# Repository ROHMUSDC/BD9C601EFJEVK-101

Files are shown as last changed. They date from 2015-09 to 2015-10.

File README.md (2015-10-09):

# BD9C601EFJEVK-101 Design Resource Repository
* Hardware Design Files and Documentation for the ROHM BD9C601EFJEVK-101 EVK

----
### Description: 
* BD9C601EFJ is a synchronous buck switching regulator with built-in low on-resistance power MOSFETs
* With wide input voltage range, It is capable of providing current of up to 6A
* It is a current mode control DC/DC converter and features high-speed transient response
* Phase compensation can also be set easily

----
### Repository Contents
* Application Note Folder: Contains Draft Version of EVK Application Note
* Design Files: Contains Board, Gerber, Schematic, and BOM information for this EVK Board
* Measurement Reports Folder: Contains measurement testing information completed for these EVK Boards

----
### Where to Purchase?
* http://www.rohm.com/web/global/distribution/-/dinventory/BD9C601EFJ_EVK/sample/0

----
### DISCLAIMER
This Technical Data is protected under copyright laws.

ROHM hereby grants you a nonexclusive, nontransferable license to use this Technical Data 
as long as you abide by the terms and conditions of this DISCLAIMER. 

However, you are not authorized to sell, loan, rent, lease, redistribute or license this Technical Data, 
in whole or in part, or in modified form, to anyone.

You may modify this Technical Data to suit your specific applications, 
but the rights to derivative works and said modifications shall belong to ROHM. 

You may make copies of this Technical Data as necessary for internal use only within your company.

In any case, the latest datasheet is considered the final design guideline and represents 
the only actual performance specifications.

ROHM shall not be responsible for ensuring proper application on all computer systems.
This Technical Data is provided AS IS. ROHM makes no guarantees, either implicitly or explicitly, 
regarding its usability, functionality, accuracy, merchantability, or fitness for a specific purpose.

In addition, you shall take full responsibility for the use of any information acquired from this Technical Data. 

ROHM does not assume warranty of any kind arising from the use of this Technical Data. ACCORDINGLY, 
IN NO EVENT SHALL ROHM BE RESPONSIBLE, WHETHER THROUGH CONTRACT OR TORT LIABILITY, 
FOR ANY DAMAGES (INCLUDING BUT NOT LIMITED TO LOST PROFITS OR OTHER INCIDENTAL, CONSEQUENTAL, 
OR PUNITIVE DAMAGES) ARISING OUT OF OR IN CONNECTION WITH THE USE OR APPLICATION OF THIS Technical Data.

Furthermore, this Technical Data is subject to change without notice.

Unless otherwise expressly provided herein, ROHM does not convey any license under patent rights 
or any other intellectual property rights (including those of third parties).

ROHM is not obligated to provide maintenance or support for the Technical Data.

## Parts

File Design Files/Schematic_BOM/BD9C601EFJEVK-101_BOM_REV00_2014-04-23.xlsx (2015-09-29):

BD9C601EFJEVK-101
Revision: 00
Bill Of Materials | Page1
Item | Quantity | Reference | Part | PCB Footprint | DESCRIPTION | MANUFACTURER1 | MANUFACTURER1_PART# | DISTR1 | DISTR1_PART# | DNP | Provided by ROHM | ROHM Comment
1 | 1 | C1 | 0.1uF | C0603 | CAP CER 0.1UF 25V 10% X7R 0603 | Murata | GRM188R71E104KA01D | DIGIKEY | 490-1524-2-ND |  | Y
2 | 1 | C2 | 10uF | C1206 | CAP CER 10UF 25V 20% X5R 1206 | Murata | GRM31CR61E106MA12L | DIGIKEY | 490-5423-1-ND |  | Y
3 | 2 | C3,C4 | 22uF | C1206 | CAP CER 22UF 16V 10% X5R 1206 | Murata | GRM31CR61C226KE15K | DIGIKEY | 490-6512-1-ND |  | Y
4 | 1 | C5 |  | C0603 |  |  |  |  |  | DNP( Do not place)
5 | 1 | C6 | 1500pF | C0603 | CAP CER 1500PF 50V 10% X7R 0603 | Murata | GRM188R71H152KA01D | DIGIKEY | 490-1498-2-ND |  | Y
6 | 1 | C7 |  | C1206 |  |  |  |  |  | DNP( Do not place)
7 | 1 | C8 |  | C0805 |  |  |  |  |  | DNP( Do not place)
8 | 2 | D1,D3 | RB085B-30TL | CPD | DIODE SCHOTTKY 30V 10A CPD | Rohm | RB085B-30TL | DIGIKEY | RB085B-30TLCT-ND | DNP( Do not place) | Y
9 | 1 | D2 | SMAJ16A | DO-214AC | TVS DIODE 16VWM 26VC SMA | Littelfuse Inc | SMAJ16A | DIGIKEY | SMAJ16ALFTR-ND |  | N
10 | 1 | J1 | 87224-3 | HDR_THVT_1X3_100 | CONN HEADER VERT .100 3POS 15AU | TE Connectivity Div | 87224-3 | DIGIKEY | A26545-ND |  | N
11 | 1 | L1 | 3.3uH | SMT_7P1X6P5 | INDUCTOR 3.3UH 6.8A 20% SMD | TDK Corporation | SPM6530T-3R3M | DIGIKEY | 445-4119-2-ND |  | Y
12 | 1 | R1 | 20K | R0603 | RES 20K OHM 1/10W 1% 0603 SMD | Rohm | TRR03EZPF2002 | DIGIKEY | RHM20KBJTR-ND |  | Y
13 | 1 | R2 | 7.5K | R0603 | RES 7.5K OHM 1/10W 1% 0603 SMD | Rohm | MCR03ERTF7501 | DIGIKEY | RHM7.50KCFTR-ND |  | Y
14 | 1 | R3 | 2.4K | R0603 | RES 2.4K OHM 1/10W 1% 0603 SMD | Rohm | MCR03ERTF2401 | DIGIKEY | RHM2.40KCFTR-ND |  | Y
15 | 2 | TP1,TP3 | TP_63Mil_TH | TP_TH | TEST POINT PC MULTI PURPOSE RED | Keystone Electronics | 5010 | DIGIKEY | 5010K-ND |  | N
16 | 2 | TP2,TP4 | TP_63Mil_TH | TP_TH | TEST POINT PC MULTI PURPOSE BLK | Keystone Electronics | 5011 | DIGIKEY | 5011K-ND |  | N
17 | 1 | U1 | BD9C601EFJ | HTSOP-J8 | 4.5V to 18V Input, 6.0A Integrated MOSFET 1ch Synchronous Buck DC/DC Converter | ROHM | BD9C601EFJ |  |  |  | Y
18 | 1 | ZX1 | 0 | SM_180x060 | 1806 footprint solder-short during assembly
19 |  |  |  |  | Shunt jumper for header J1 (item #10), CONN SHUNT 2POS GOLD W/HANDLE | TE Connectivity | 881545-1 | DIGIKEY | 881545-1-ND |  | N

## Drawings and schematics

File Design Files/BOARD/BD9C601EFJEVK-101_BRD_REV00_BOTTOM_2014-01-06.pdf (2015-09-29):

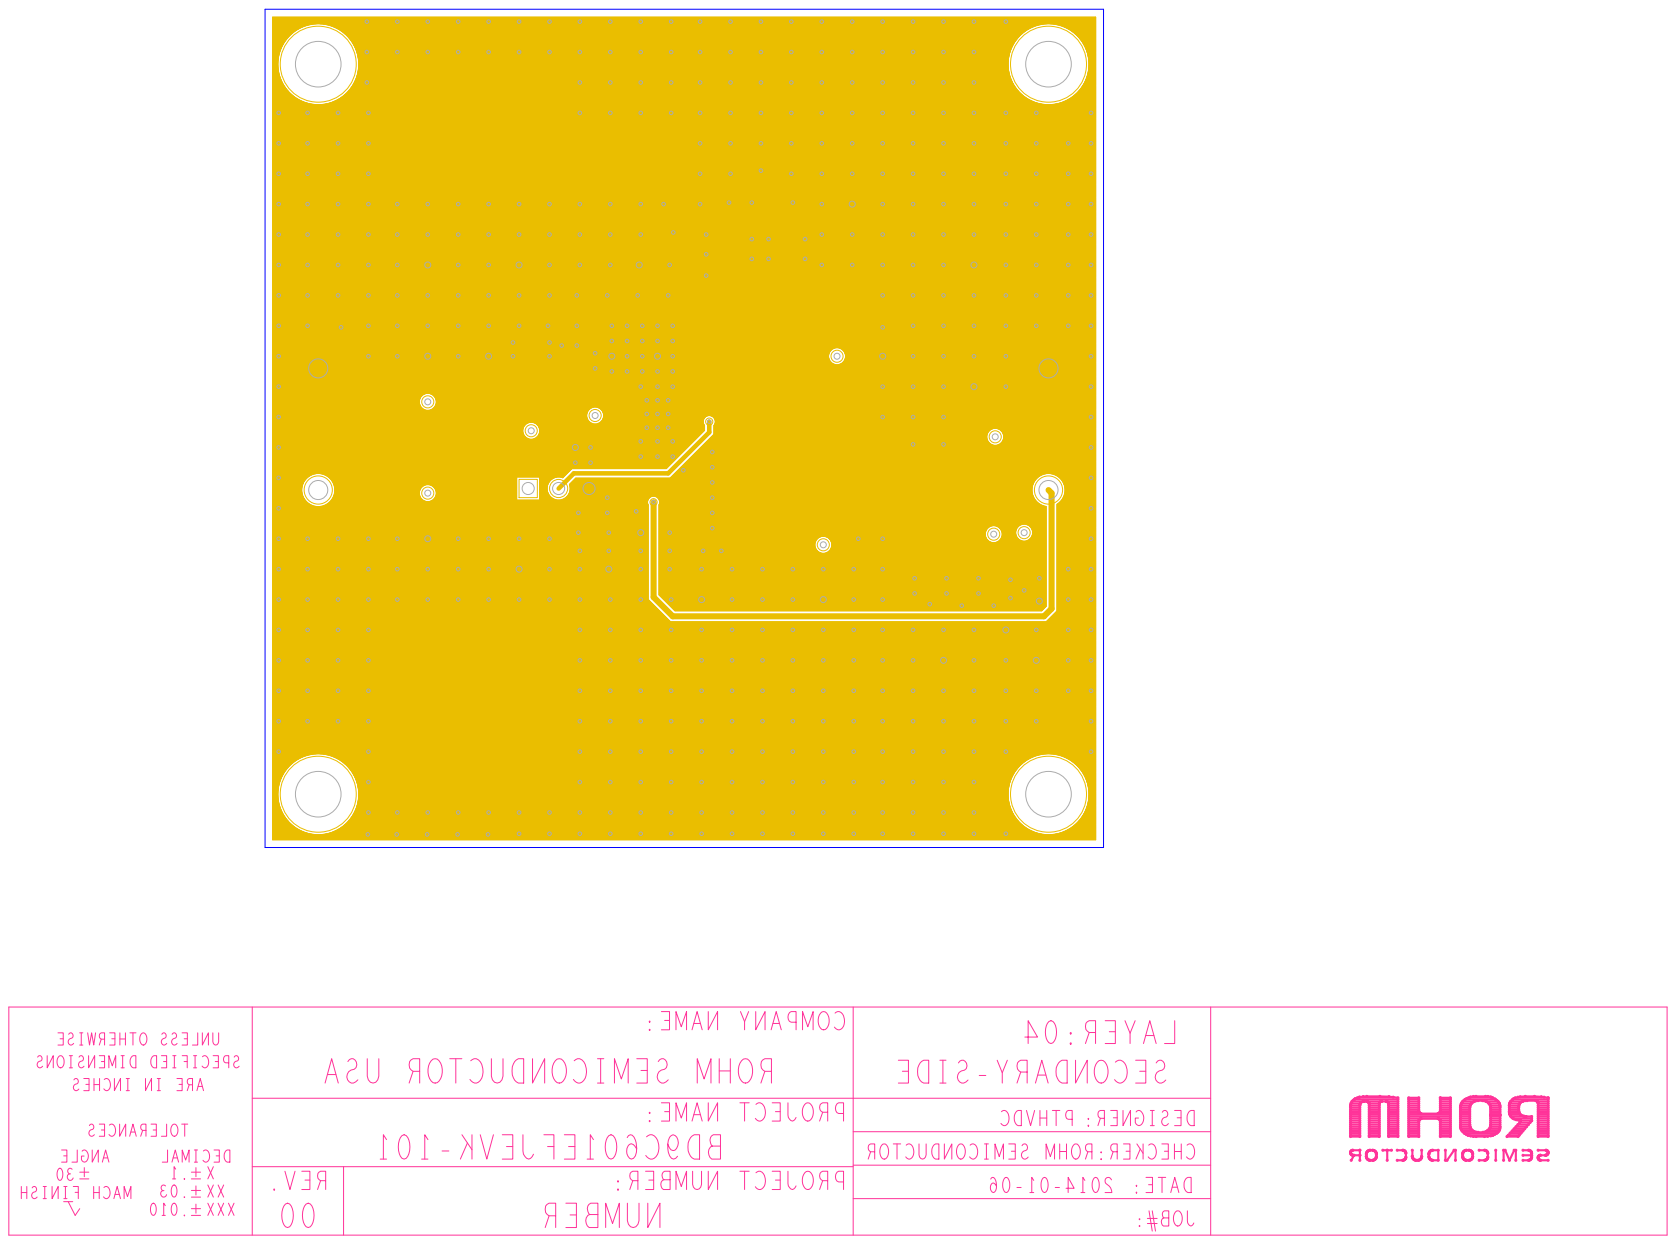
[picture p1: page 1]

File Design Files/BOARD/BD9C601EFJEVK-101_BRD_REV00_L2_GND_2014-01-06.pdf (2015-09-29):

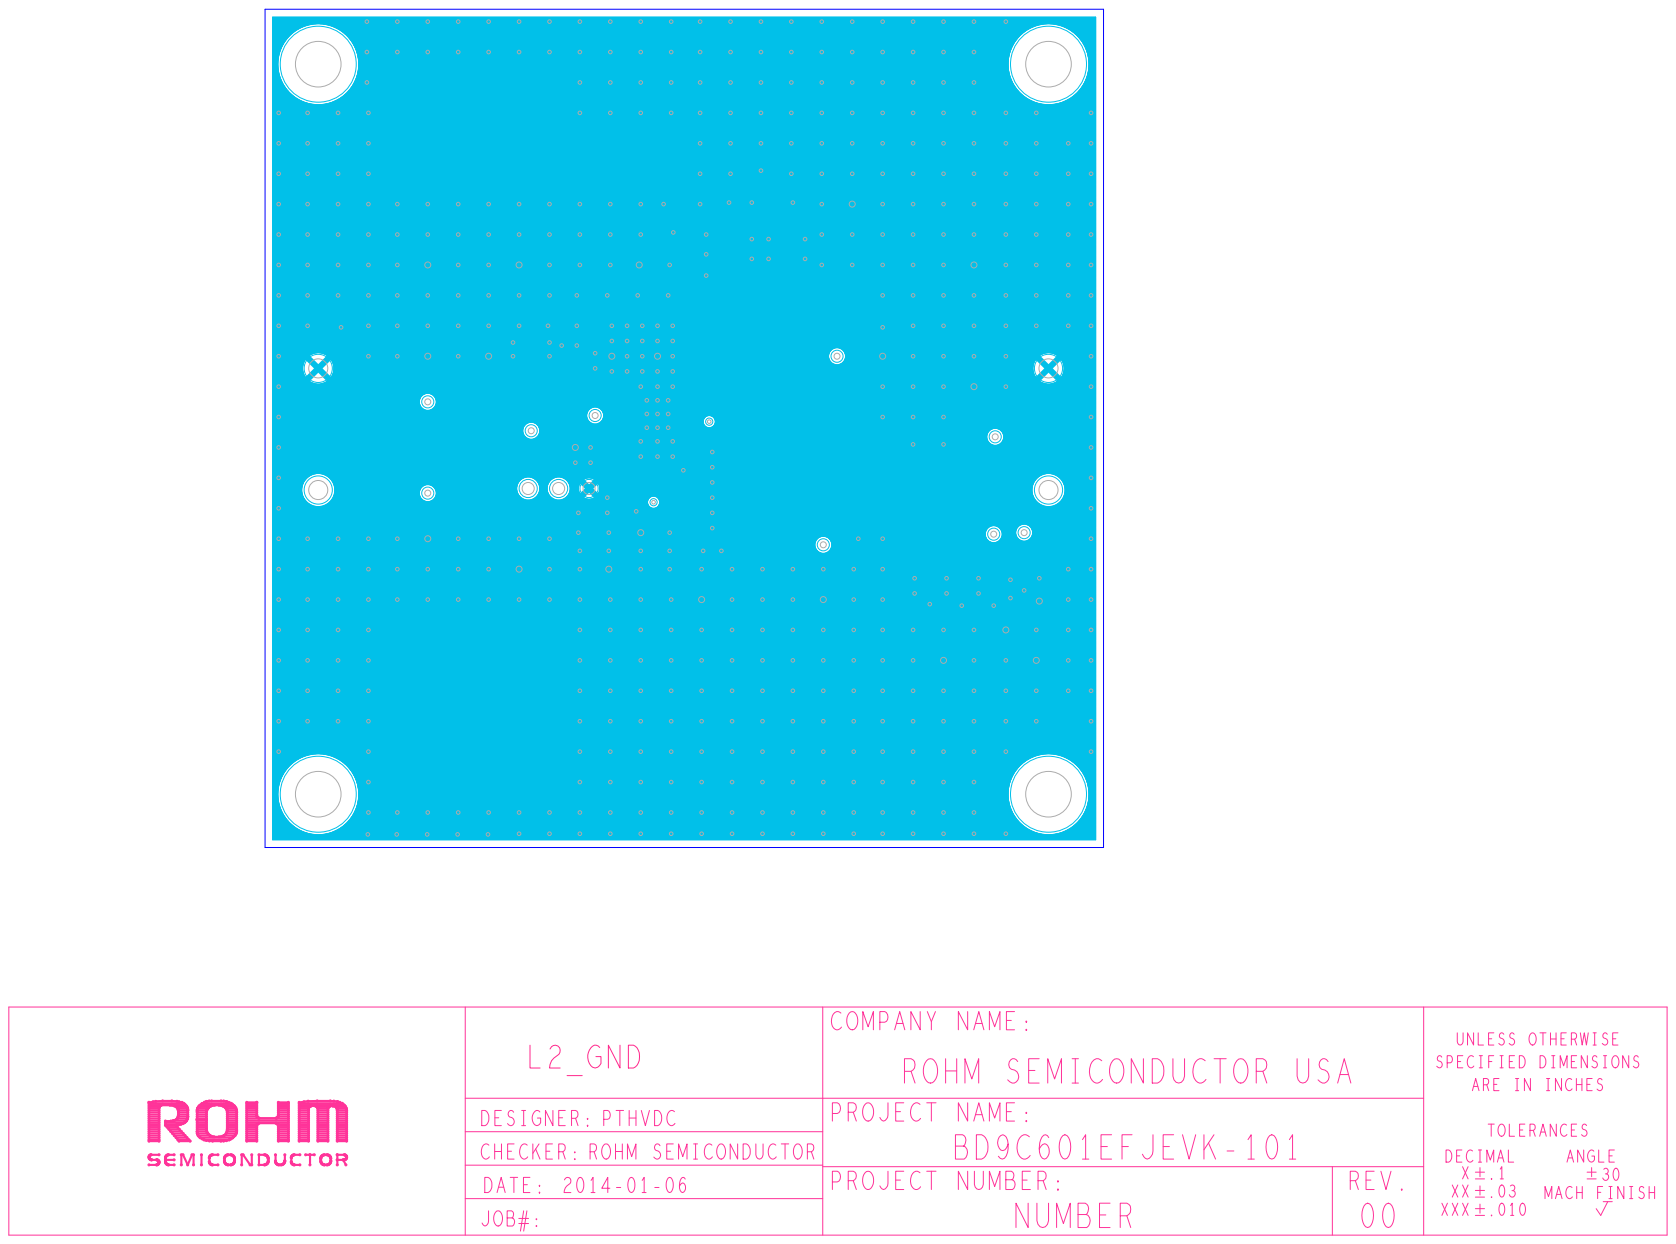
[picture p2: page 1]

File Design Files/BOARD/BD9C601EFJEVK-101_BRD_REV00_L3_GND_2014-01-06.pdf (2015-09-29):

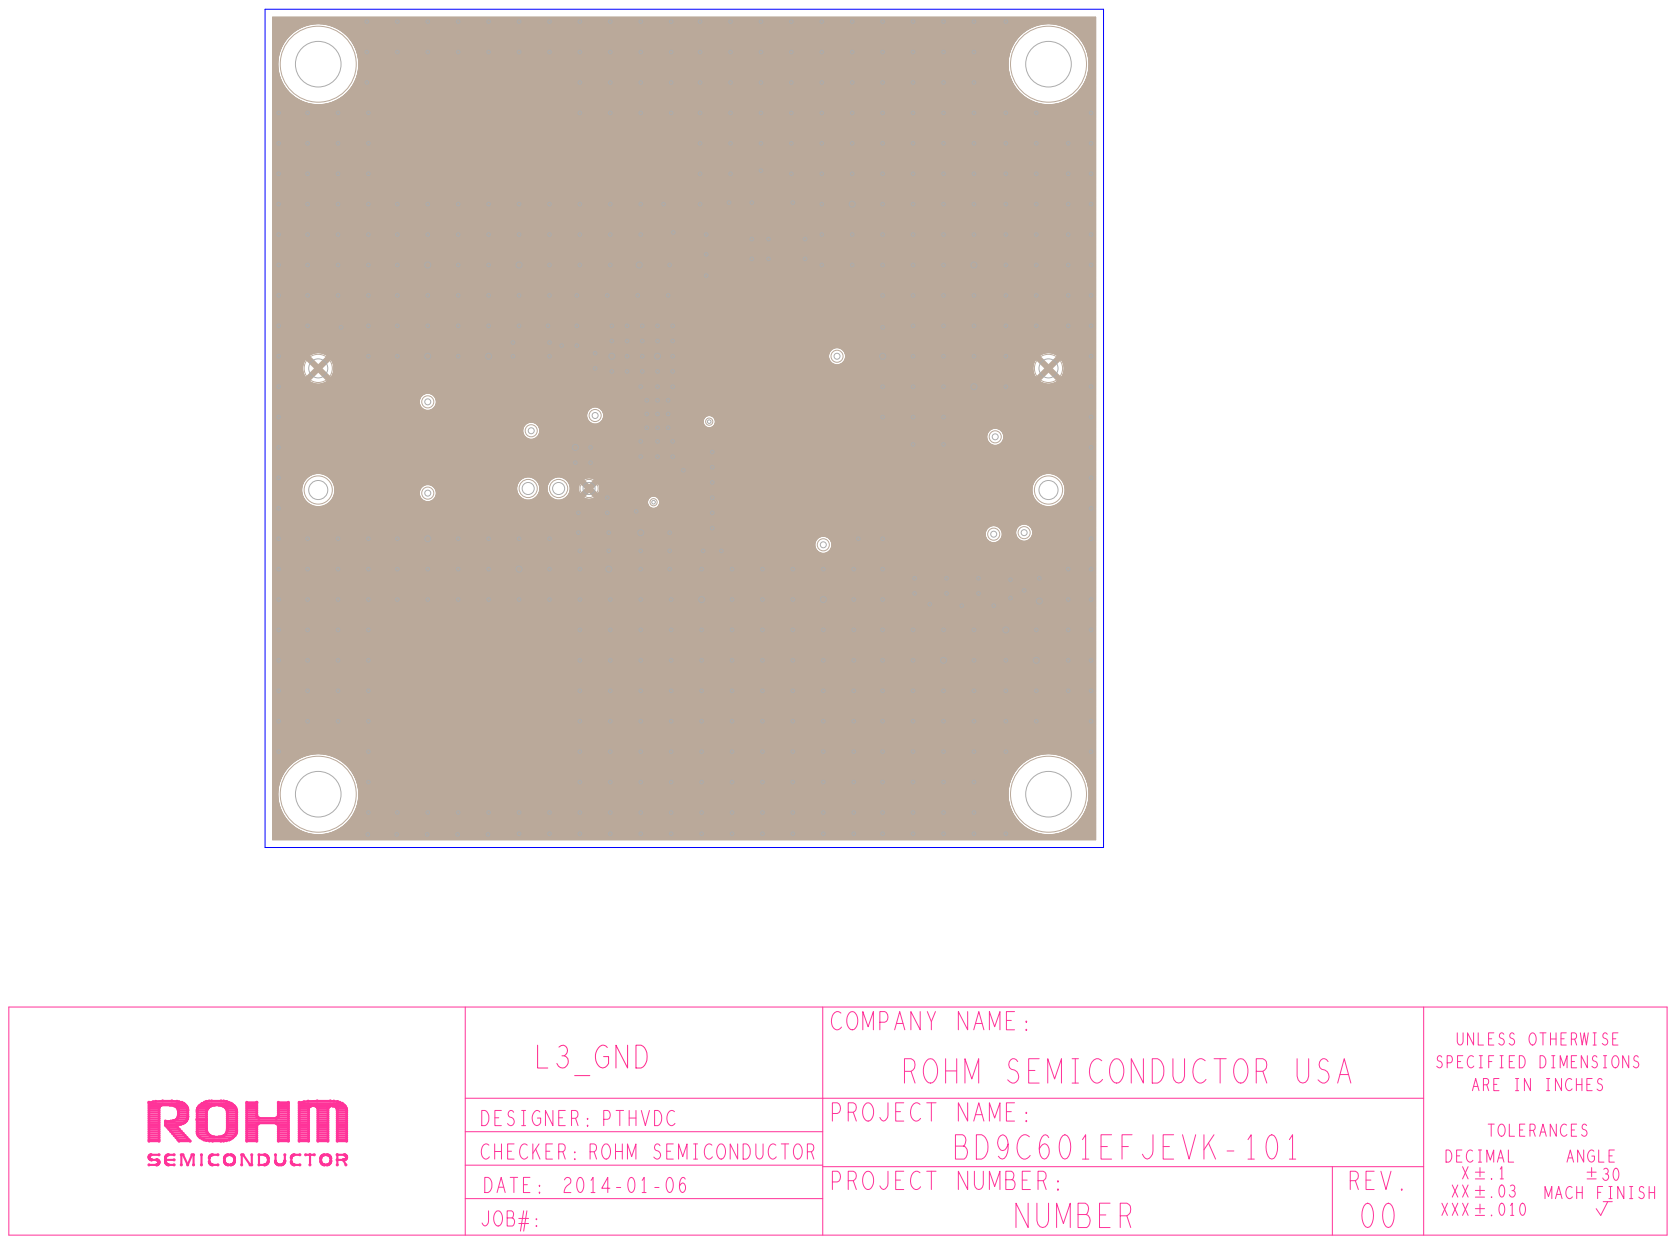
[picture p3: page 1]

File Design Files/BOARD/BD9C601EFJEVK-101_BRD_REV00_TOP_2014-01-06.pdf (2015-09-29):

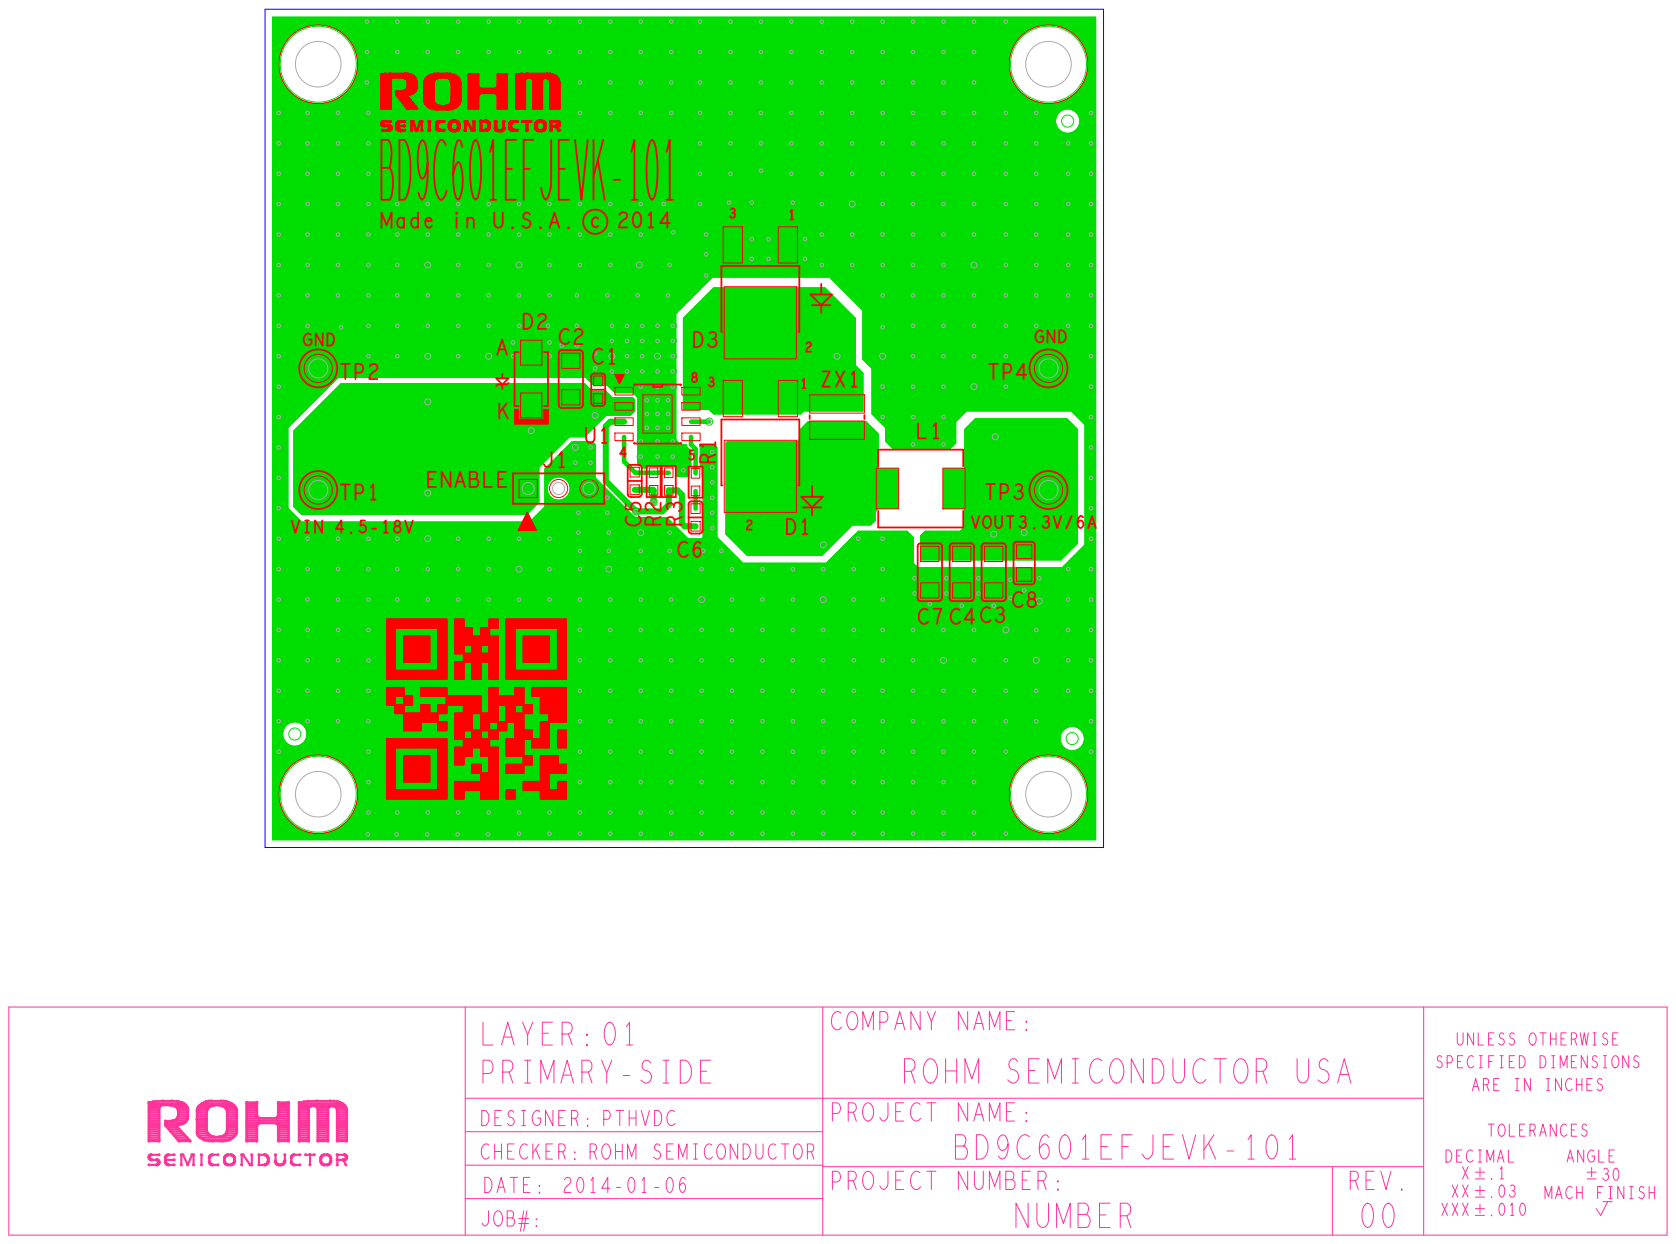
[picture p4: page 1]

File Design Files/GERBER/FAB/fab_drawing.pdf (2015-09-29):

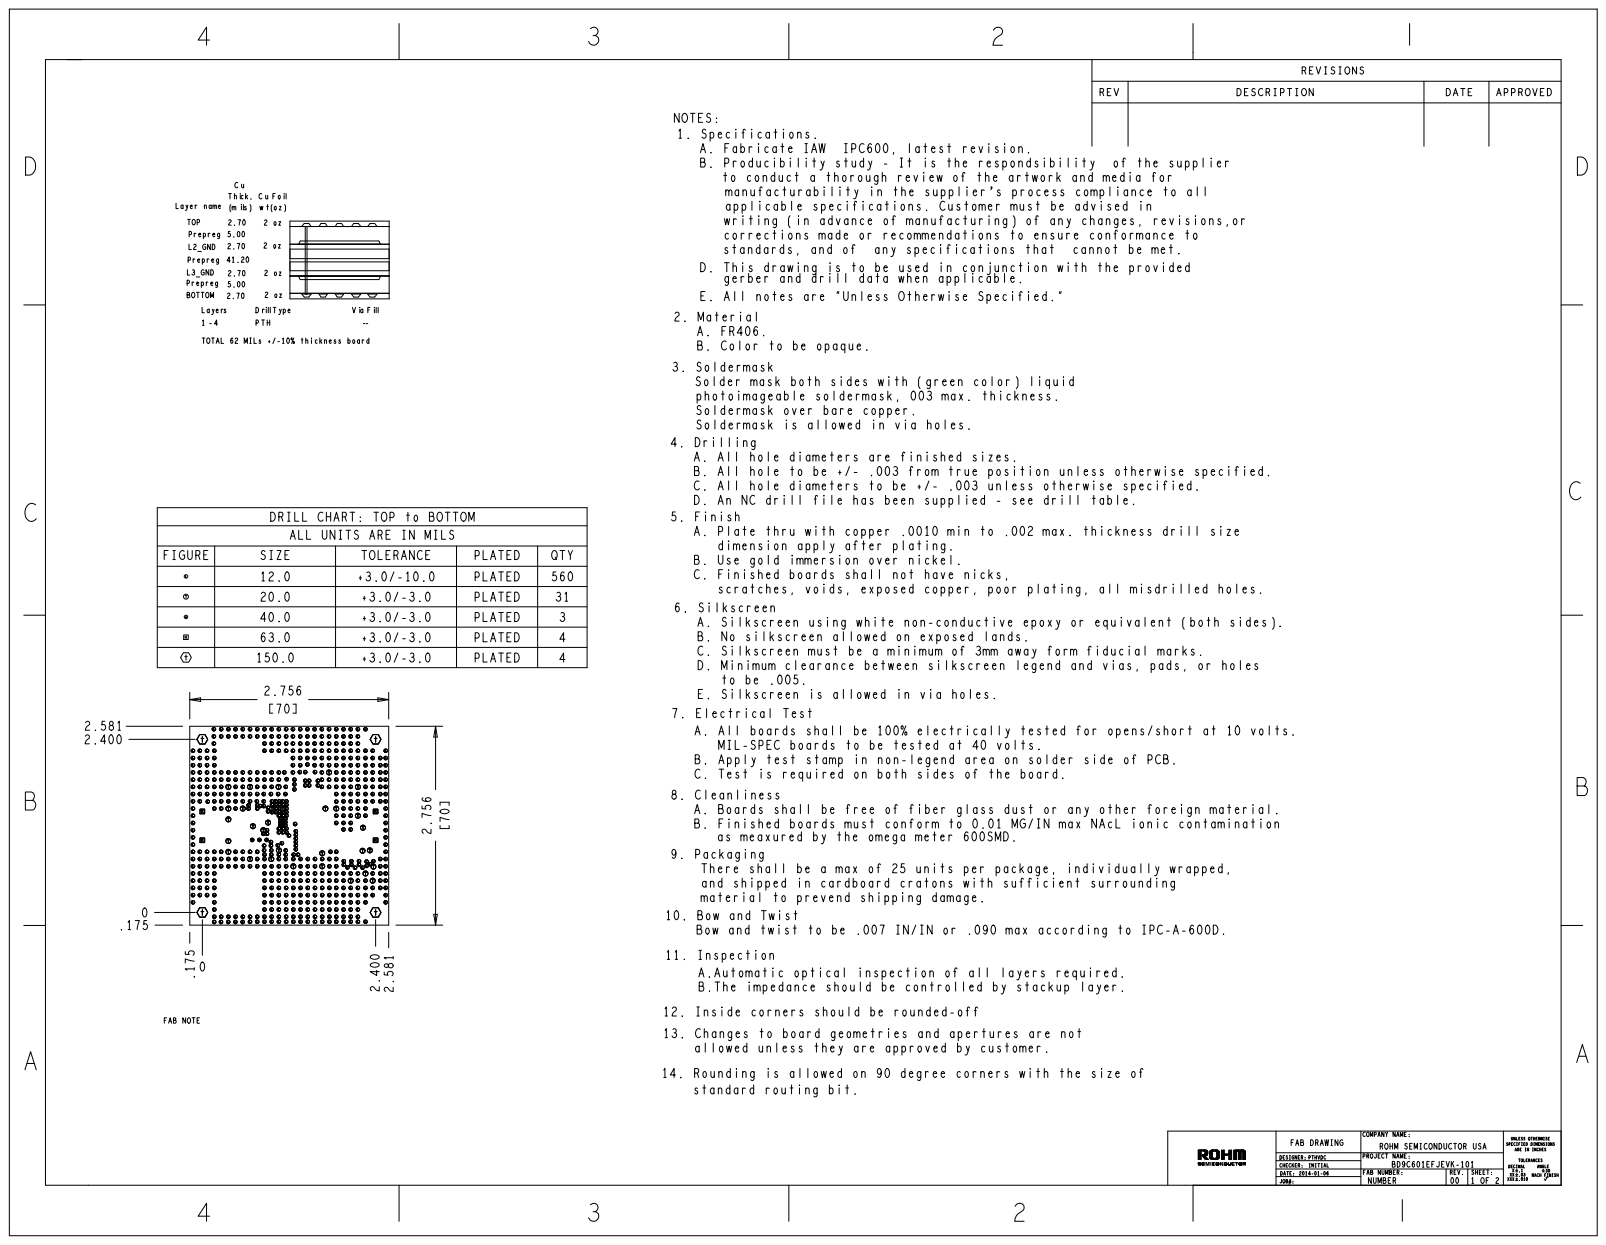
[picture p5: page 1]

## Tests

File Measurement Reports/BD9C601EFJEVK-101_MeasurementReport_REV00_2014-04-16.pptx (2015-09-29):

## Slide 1

PTH Solutions Confidential

BD9C601EFJEVK-101 Measurement Report
April 16th, 2014
Hosted by: Xuan Dang

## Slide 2

Equipment list

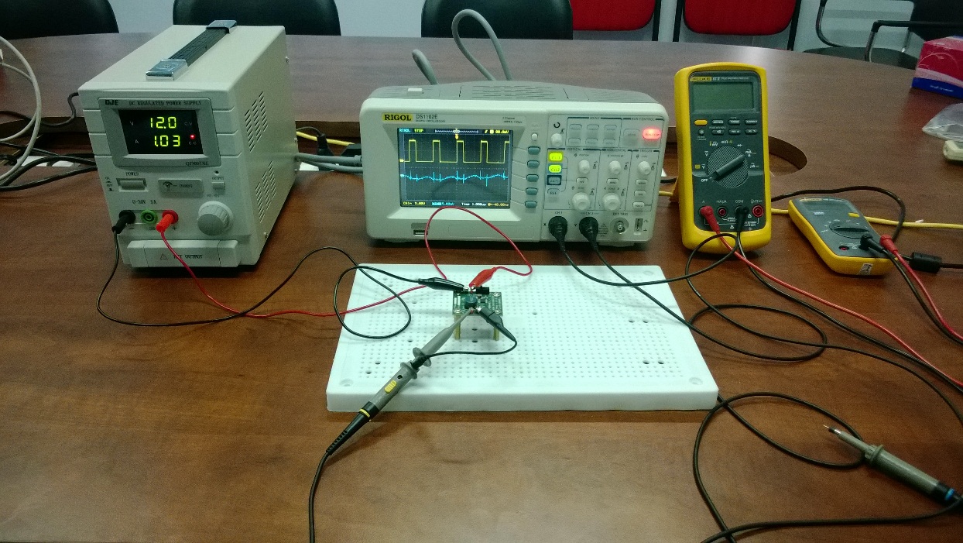
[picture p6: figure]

- Regulated DC Power Supply
  - QJE QJ3005XE (0-30V/5A)
- Multimeter:
  - Fluke 87V True RMS
  - Fluke 106
- Oscilloscope
  - Rigol DS1102E
- Electronic Load
  - B&K BK8500
- Current probe
  - RP1001C

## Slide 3

1. Functional Test

- Testing procedure
  1. Turn on the DC Supply. Set output of the DC Supply in range from 4.5V to 18V and turn it off. Connect DC the Supply to: [+]VIN(TP1) and [-]GND(TP2) of evaluation board.
  2. Connect Electronic Load to: [+]VOUT(TP3) and [-]GND(TP4). Power on Electronic Load, set input of Electronic Load to 6A.
  3. Turn on the DC Supply.
  4. Turn on load.
  5. Move J1 header to turn EN on.
- Result:
VIN = 4.5V to 18V
VOUT = 3.22V ~ 3.29V.
Test passed.

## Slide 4

2. Hot Plugging Test

- Test condition
  - VIN = 18V
  - IOUT = 6A
  - With original diode D2: SMAJ15A
- Result:
- IIN MAX= 76A
- VIN peak transient voltage is 22V > VIN Maximum Rating (20V)
- ICC quiescent current is 93mA at VIN=18V
- The IC still operate properly after 100+ test time.

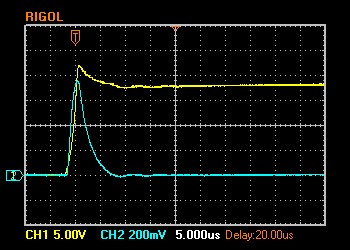
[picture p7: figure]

VIN 5V/Div. (DC)

IIN 20A/Div. (AC)

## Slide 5

2. Hot Plugging Test (cont.)

- Test condition
  - VIN = 18V
  - IOUT = 6A
  - With diode D2: SMAJ18A
- Result:
- IIN MAX= 78.4A
- VIN peak transient voltage is 26.8V > VIN Maximum Rating (20V)
- ICC quiescent current is 29mA at VIN=18V
- The IC still operate properly after 100+ test time.

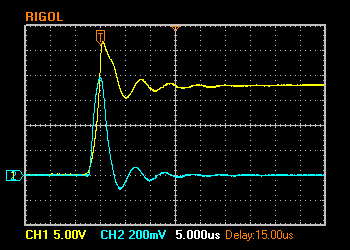
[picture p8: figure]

VIN 5V/Div. (DC)

IIN 20A/Div. (AC)

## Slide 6

2. Hot Plugging Test (cont.)

- Test condition
  - VIN = 18V
  - IOUT = 6A
  - With diode D2: SMAJ16A
- Result:
- IIN MAX= 75.2A
- VIN peak transient voltage is 23.8V > VIN Maximum Rating (20V)
- ICC quiescent current is 26mA at VIN=18V
- The IC still operate properly after 100+ test time.

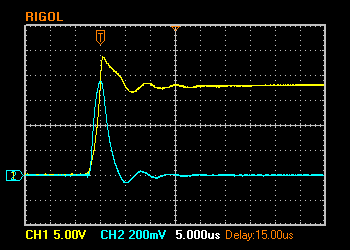
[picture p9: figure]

VIN 5V/Div. (DC)

IIN 20A/Div. (AC)

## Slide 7

2. Hot Plugging Test (cont.)

- Test condition
  - VIN = 18V
  - IOUT = 6A
  - With diode D2: SMAJ14A
- Result:
- IIN MAX= 80A
- VIN peak transient voltage is 21V > VIN Maximum Rating (20V)
- ICC quiescent current is 200mA at VIN=18V

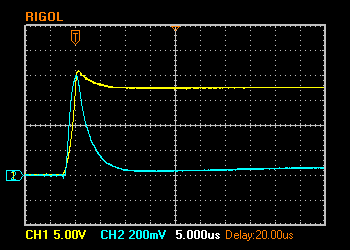
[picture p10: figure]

VIN 5V/Div. (DC)

IIN 20A/Div. (AC)

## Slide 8

2. Hot Plugging Test (cont.)

- Test condition
  - VIN = 18V
  - IOUT = 6A
  - With diode D2: SMAJ13A
- Result:
- IIN MAX= 82.4A
- VIN peak transient voltage is 18.8V < VIN Maximum Rating (20V)
- ICC quiescent is 380mA at VIN=18V

VIN 5V/Div. (DC)

IIN 20A/Div. (AC)

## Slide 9

3. Circuit Quiescent Current Measurement

- Test condition
  - VIN = 0-18V
  - Room temperature 25oC

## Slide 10

4. Efficiency Measurements

- Test condition
  - VIN = 12V
  - VOUT = 3.3V
  - With SMAJ15A
  - Room temperature 25oC

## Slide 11

5. Load Response Measurements

Load response characteristic
(VIN=12V, VOUT=3.3V, IOUT=0 → 6A)

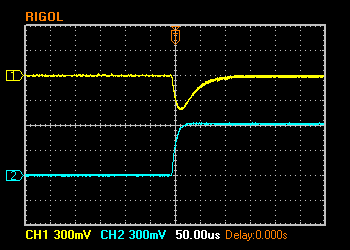
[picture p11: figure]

VOUT 300mV/Div. (AC)

IOUT 3A/Div. (DC)

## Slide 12

5. Load Response Measurements (cont.)

Load response characteristic
(VIN=12V, VOUT=3.3V, IOUT=6A → 0)

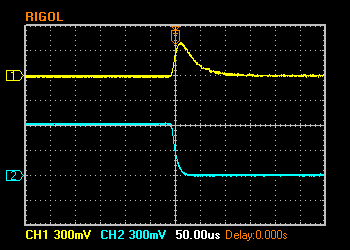
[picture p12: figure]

VOUT 300mV/Div. (AC)

IOUT 3A/Div. (DC)

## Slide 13

6. Ripple Response Measurements

VOUT Ripple voltage
(VIN=12V, VOUT=3.3V, IOUT=6A)

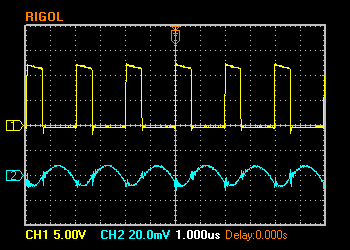
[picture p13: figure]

VSW 5V/Div. (DC)

VOUT 20mV/Div. (AC)

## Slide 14

6. Ripple Response Measurements (cont.)

VOUT Ripple voltage
(VIN=12V, VOUT=3.3V, IOUT=0A)

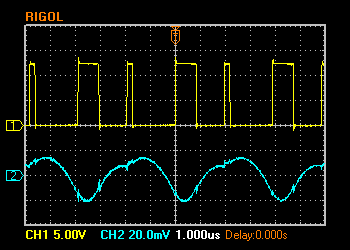
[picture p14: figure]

VSW 5V/Div. (DC)

VOUT 20mV/Div. (AC)

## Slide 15

7. Input Voltage Ripple Measurements

VIN Ripple voltage
(VIN=12V, VOUT=3.3V, CIN=10uF+ 0.1uF, IOUT=6A)

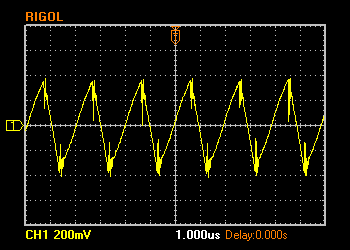
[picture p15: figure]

VIN 200mV/Div. (AC)

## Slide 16

7. Input Voltage Ripple Measurements (cont.)

VIN Ripple voltage
(VIN=12V, VOUT=3.3V, CIN=10uF + 0.1uF, IOUT=0A)


VIN 50mV/Div. (AC)
